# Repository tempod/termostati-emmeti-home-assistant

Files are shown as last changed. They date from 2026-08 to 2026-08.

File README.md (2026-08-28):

# Fancoil Emmeti in Home Assistant via ESPHome

Integrazione di fancoil **Emmeti** in Home Assistant tramite ESPHome, usando un
ESP8266 come master Modbus RTU su RS485 verso il comando a muro.

Il pannello a muro **resta pienamente utilizzabile**: questa configurazione lo
affianca invece di sostituirlo, e i due lati restano allineati in entrambe le
direzioni. Quello che si fa dal pannello compare in Home Assistant, e viceversa.

> **Nota sulle marche.** Lo stesso comando a muro viene rivenduto da diversi
> produttori con codici e marchi differenti, e il protocollo Modbus è con ogni
> probabilità identico. Questo codice però è stato provato **solo su Emmeti**:
> su altri marchi dovrebbe funzionare, ma non è verificato.

## Come è fatto

```
Home Assistant  ──WiFi──  D1 mini (ESPHome)  ──RS485──  comando a muro  ──  fancoil
```

L'ESP non parla direttamente con la scheda del fancoil, ma con il comando a
muro, che a sua volta fa da master verso le unità a valle. È un master che
dialoga con un altro master: da qui derivano diverse particolarità descritte più
avanti.

Il componente `climate` di ESPHome fa da facciata verso Home Assistant. Non
regola nulla per conto proprio: traduce le richieste dell'utente in scritture sui
registri del pannello e riflette in Home Assistant ciò che il pannello riporta.

## Schema di collegamento

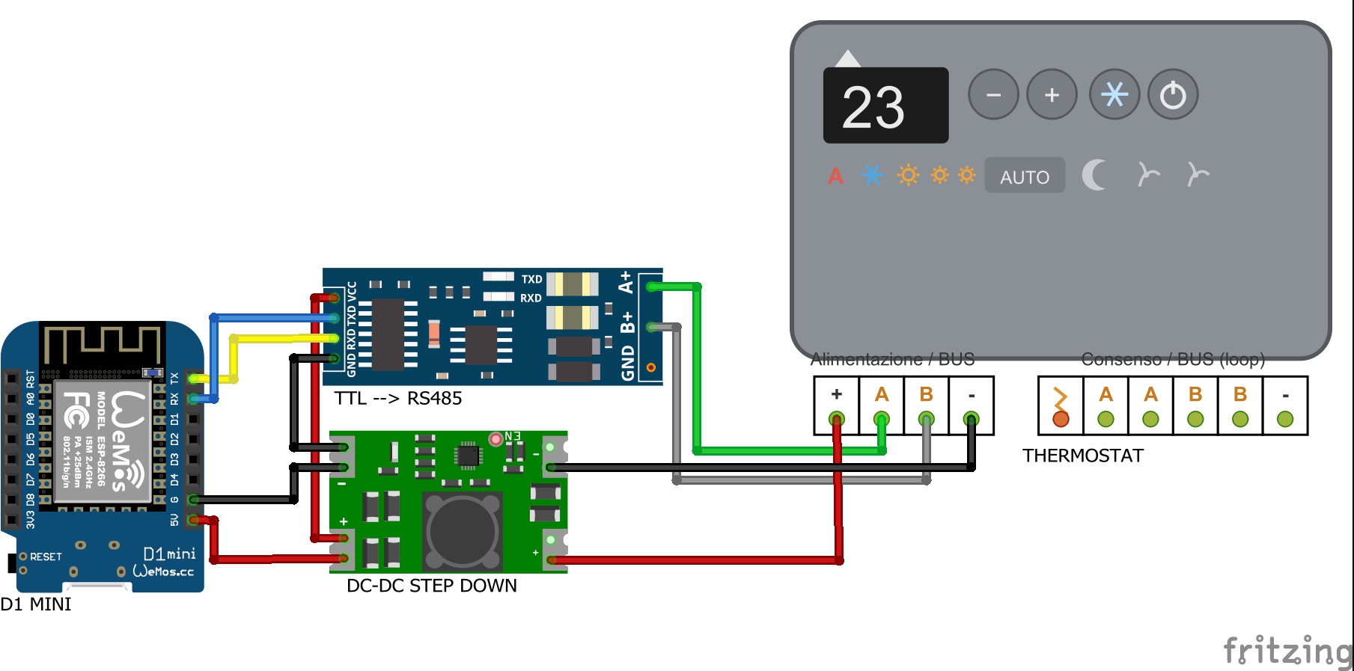
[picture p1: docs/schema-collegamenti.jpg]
Schema di collegamento


### Componenti

* D1 mini (ESP8266)
* Convertitore TTL → RS485
* Step down DC-DC

### Note di cablaggio

L'alimentazione viene prelevata dai morsetti `+` e `-` del bus del pannello e
portata a 5 V dallo step down, che alimenta sia il D1 mini sia il convertitore:
non serve un alimentatore dedicato.

Lato seriale, `TX` del convertitore va su `D1` e `RX` su `D2`; lato bus, `A+` e
`B+` vanno ai morsetti `A` e `B` del pannello e `GND` al `-`.

Il bus lavora a 9600 8N1. Il manuale prescrive cavo bipolare schermato da almeno
0,35 mm², lunghezza totale entro i 500 m, linea terminata con la resistenza da
120 Ω in dotazione, tenuta separata dai cavi di potenza, e vieta i collegamenti a
stella.

## Entità esposte

| Entità | Tipo | Registro |
|---|---|---|
| Termostato | `climate` | vari |
| Temperatura Attuale | `sensor` | 0 |
| Temperatura Richiesta | `number` | 231 |
| Velocità Ventola | `select` | 201 |
| Stagione | `select` | 233 |
| Offset Temperatura Ambiente | `number` | 242 |
| Indirizzo Modbus | `number` | 200 |
| Accensione | `switch` | 201 |
| Modo Notte | `switch` | 201 |
| Stati / Allarme | `text_sensor` | 104 / 105 |
| Standby (STAT) | `binary_sensor` | 104 bit 11 |
| Segnale WiFi, Restart | diagnostica | — |

## Installazione

1. Creare in `secrets.yaml` le voci `wifi_ssid`, `wifi_password`,
   `wifi_password_fallback`, `encryptionkey`, `ota_password`.
2. Copiare il file YAML e adattare il blocco `substitutions`.
3. Compilare e caricare con ESPHome.

Per aggiungere un altro fancoil basta duplicare il file e cambiare le
`substitutions` (più la porta syslog, se lo si usa). Tutto il resto è identico.

```yaml
substitutions:
  devicename: clima-salotto
  ip: 192.168.1.152
  upti: 3s      # intervallo di polling Modbus
  adr: 0x1      # indirizzo del pannello sul proprio bus
```

## Diagnostica opzionale via syslog

In fondo alla sezione `logger` c'è un blocco syslog commentato. Scommentandolo,
il dispositivo invia i log via UDP al
[Syslog Receiver](https://github.com/zollak/homeassistant-syslog-receiver) di
Home Assistant. La porta è univoca per dispositivo (`5` + ultimo terzetto dell'IP), così ogni termostato finisce in un'istanza separata e i log restano
distinti senza bisogno di filtrare per indirizzo sorgente.

Serve soprattutto per diagnosticare eventi che accadono mentre nessuno guarda —
come le accensioni spontanee descritte più sotto — perché ESPHome non conserva
log sul dispositivo.

## Particolarità del protocollo

Sono i punti che hanno richiesto più lavoro, riportati qui perché non sono
evidenti dal manuale e possono servire a chi parte da zero.

### Il registro 201 è un registro di flag

Non è un elenco di valori alternativi, ma un insieme di bit:

| Bit | Significato |
|---|---|
| 0-1 | Velocità: 0 Auto, 1 Silenzioso, 2 Notturno, 3 Massimo |
| 4 | LOCK (tastiera del pannello bloccata) |
| 7 | Stby (macchina in standby) |
| 8-15 | Riservati di sistema — **da non modificare** |

Scriverlo come valore intero (per esempio `128` per lo standby) azzera i bit
riservati e il flag LOCK. Va aggiornato in **read-modify-write**: si parte
dall'ultimo valore letto e si toccano solo i bit necessari, con la maschera
`0xFF7C`.

Conseguenza pratica: lo standby non è un valore unico. Una macchina spenta con
velocità Massimo vale `131`, non `128`. Una `optionsmap` statica non copre questi
casi e lascia l'entità senza stato.

### Il pannello si riaccende quando l'ESP si riavvia

Verificato dai log: alla prima lettura utile dopo un riavvio, il registro 201
riporta già la macchina accesa e con velocità azzerata ad Auto, prima che
l'ESP abbia scritto qualsiasi cosa. Non è un timeout di comunicazione (il
manuale ne documenta uno da 300 secondi, per tutt'altra configurazione): il
pannello esce da solo dallo standby appena il master sparisce dal bus.

Non è quindi evitabile lato software. La configurazione lo **corregge a
posteriori**:

- `desired_on` e `desired_speed` sono salvati in flash e sopravvivono al riavvio;
- alla prima lettura dopo il boot, se lo stato letto non coincide con quello
  salvato, viene riscritto con una sola operazione;
- `boot_sync_done` blocca ogni scrittura sul bus finché lo stato reale
  dell'unità non è noto, così l'OFF applicato all'avvio non spegne per errore
  una macchina che stava lavorando.

Effetto residuo: dopo un riavvio a macchina spenta, il pannello resta acceso per
circa 2-3 secondi prima di tornare in standby. È il tempo di boot dell'ESP più
un ciclo di polling, e non si può comprimere ulteriormente.

### Il registro stagione non ha uno stato "spento"

Il registro 233 vale solo Inverno o Estate. Poiché `on_value` si attiva ad ogni
pubblicazione — non solo quando il valore cambia — senza una guardia sullo
standby ogni ciclo di polling riaccenderebbe il componente `climate`.

### Un setpoint solo, due nel climate

Il pannello espone un unico setpoint (registro 231), mentre il componente
`climate` di ESPHome con due modalità ne gestisce due. La configurazione propaga
di volta in volta quello attivo secondo la stagione corrente.

## Crediti

Il punto di partenza di questo progetto è
[jjdejong/esphome-airleaf](https://github.com/jjdejong/esphome-airleaf), un
controller ESPHome per fancoil Innova Airleaf. Grazie all'autore per il lavoro di
mappatura iniziale dei registri.

Questa versione è pensata per il collegamento tramite comando a muro e aggiunge
la gestione a bit del registro 201, la persistenza dello stato attraverso i
riavvii e la sincronizzazione bidirezionale con il pannello.

## Riferimenti

- [Manuale Innova N273025C](docs/EDA649-EDB649-ECA644-ECA647.pdf) —
  collegamento e registri Modbus dei comandi EDA649, EDB649, ECA644, ECA647
- [Foto del comando a muro (interno) usato in questo progetto](docs/termostato-emmeti-interno.jpg)
- [Foto del comando a muro (esterno) usato in questo progetto](docs/termostato-emmeti-esterno.jpg)
- [Scheda su Home Assistant](docs/termostato-salotto-ha.jpg)
- [Documentazione ESPHome — Modbus Controller](https://esphome.io/components/modbus_controller.html)

## Licenza

Distribuito con licenza MIT. Vedi il file [LICENSE](LICENSE).

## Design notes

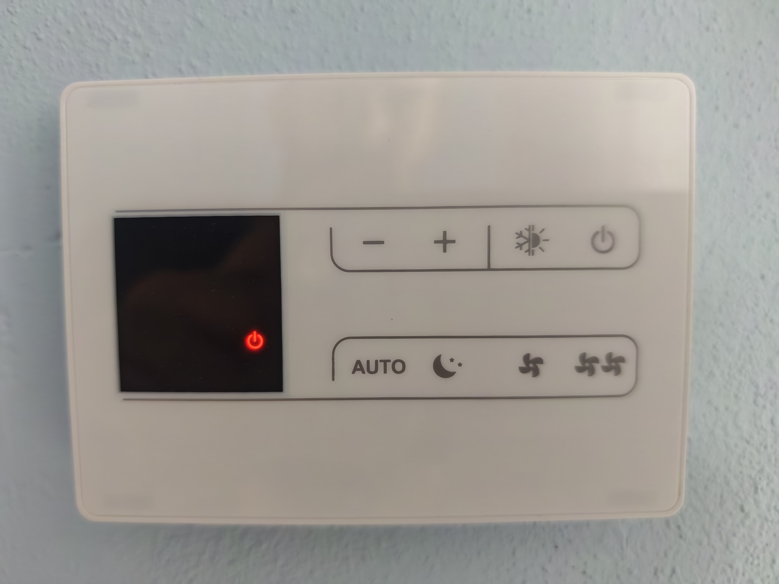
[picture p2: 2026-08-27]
docs/termostato-emmeti-esterno.jpg

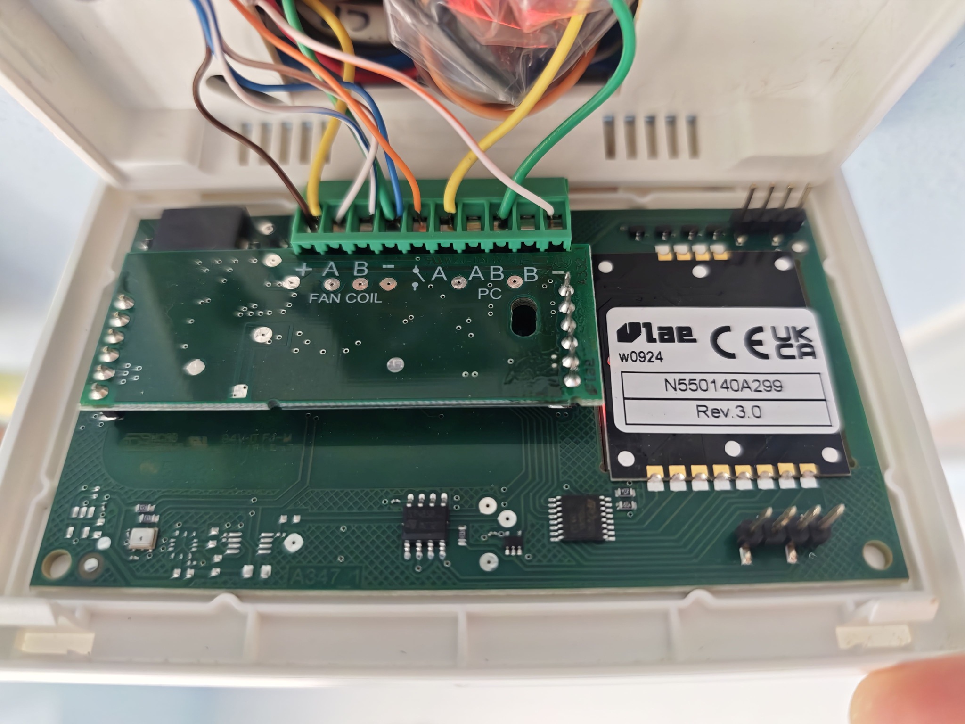
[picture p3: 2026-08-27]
docs/termostato-emmeti-interno.jpg

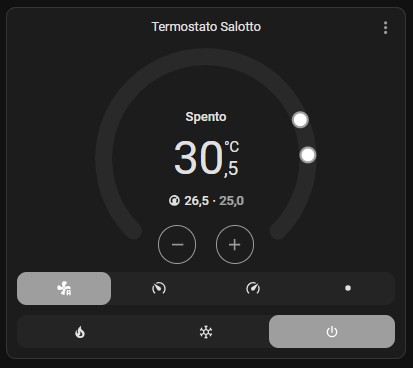
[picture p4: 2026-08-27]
docs/termostato-salotto-ha.jpg

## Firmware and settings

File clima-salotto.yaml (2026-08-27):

# =============================================================================
# Termostato fancoil Innova/Airleaf su Home Assistant tramite ESPHome
# =============================================================================
# Un D1 mini (ESP8266) fa da master Modbus RTU su RS485 verso il comando a muro
# EDA649/EDB649, che a sua volta pilota il fancoil. Il pannello resta pienamente
# utilizzabile: questa configurazione lo affianca, non lo sostituisce, e i due
# restano allineati in entrambe le direzioni.
#
# Nota sul comportamento del pannello: quando il master Modbus sparisce (cioe' ad
# ogni riavvio dell'ESP) il pannello esce da solo dallo standby e azzera la
# velocita' ventola. Lo stato voluto va quindi conservato nella flash dell'ESP e
# ri-applicato al primo contatto utile. Vedi i globals in fondo al file.
# =============================================================================

# Unici valori da cambiare per replicare la configurazione su un altro fancoil.
substitutions:
  devicename: clima-salotto
  ip: 192.168.1.152
  # Intervallo di polling Modbus.
  upti: 3s
  # Indirizzo Modbus del pannello (ogni pannello e' solo sul proprio bus).
  adr: 0x1

esphome:
  name: ${devicename}
  friendly_name: ${devicename}

esp8266:
  board: d1_mini

logger:
  # La UART hardware serve al bus RS485: nessun log su seriale.
  baud_rate: 0

# Log via rete verso il Syslog Receiver di Home Assistant. Da scommentare solo
# quando serve diagnosticare: la porta e' univoca per dispositivo (5 + ultimo
# ottetto dell'IP) cosi' ogni termostato finisce in un'istanza separata.
#syslog
#time:
#  platform: sntp
#udp:
#  addresses: 192.168.1.249
#syslog:
#  port: 5152
#syslog

api:
  encryption:
    key: !secret encryptionkey

ota:
  - platform: esphome
    password: !secret ota_password

wifi:
  ssid: !secret wifi_ssid
  password: !secret wifi_password
  fast_connect: true
  # IP statico: serve al syslog e rende prevedibile l'indirizzo per l'OTA.
  manual_ip:
    static_ip: ${ip}
    gateway: 192.168.1.1
    subnet: 255.255.255.0
  # Hotspot di emergenza se il WiFi non e' raggiungibile.
  ap:
    ssid: "$devicename Fallback Hotspot"
    password: !secret wifi_password_fallback

captive_portal:

web_server:
  port: 80

# --- Bus RS485 verso il comando a muro ---------------------------------------
# Parametri imposti dal protocollo del pannello: 9600 8N1.
uart:
  tx_pin: D1
  rx_pin: D2
  baud_rate: 9600
  stop_bits: 1
  data_bits: 8
  parity: NONE

modbus:

modbus_controller:
  - id: airleaf
    address: ${adr}
    update_interval: ${upti}
    # Pausa fra comandi consecutivi: il pannello non regge raffiche piu' fitte.
    command_throttle: 100ms
    setup_priority: -10

# --- Componente climate ------------------------------------------------------
# Il termostato di ESPHome fa da facciata verso Home Assistant: non regola nulla
# da solo, ma traduce le richieste dell'utente in scritture sui registri del
# pannello, e viceversa riflette in HA cio' che viene fatto dal pannello a muro.
climate:
  - platform: thermostat
    name: "${devicename} Termostato"
    id: airleaf_climate
    sensor: air_temperature
    set_point_minimum_differential: 5
    visual:
      temperature_step: 0.5

    # Le azioni caldo/freddo/idle sono solo tracciate a log: a comandare la
    # macchina e' il pannello, non la logica di regolazione di ESPHome.
    cool_action:
      - logger.log: "Cooling activated"
    min_cooling_off_time: 1s
    min_cooling_run_time: 1s

    heat_action:
      - logger.log: "Heating activated"
    min_heating_off_time: 1s
    min_heating_run_time: 1s

    idle_action:
      - logger.log: "Idle activated"
    min_idle_time: 1s

    # Spegnimento: mette la ventola in standby sul dispositivo.
    # La guardia su boot_sync_done impedisce che l'OFF applicato all'avvio (vedi
    # default_preset) venga scritto sul bus prima di conoscere lo stato reale.
    off_mode:
      - if:
          condition:
            lambda: 'return id(boot_sync_done) && id(fan_mode).current_option() != "Standby";'
          then:
            - select.set:
                id: fan_mode
                option: "Standby"
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

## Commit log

2026-08-27 Add Home Assistant board link to README
    Added a link to the Home Assistant board in the documentation.
2026-08-28 Fix typo in syslog port description
    Corrected the description of the unique port for devices in the syslog section.
